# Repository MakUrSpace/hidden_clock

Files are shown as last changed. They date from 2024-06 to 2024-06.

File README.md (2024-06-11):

# [Hidden Clock](https://github.com/makurspace/hidden_clock)

This is a project to build clock. Driven by a ESP32C3, using a 3D printed light diffuser and a NeoPixel LED ring, this clock will display the hour and minute as shadowed numbers in glowing hexagons.

### Working Example!
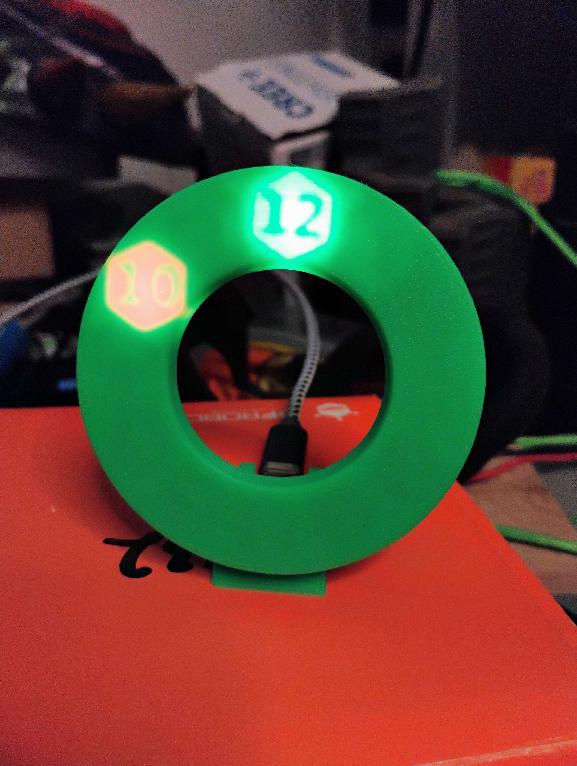
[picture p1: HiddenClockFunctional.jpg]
Working Hidden Clock


## External Parts

* [24x NeoPixel Ring](https://www.adafruit.com/product/1586)
  * A different ring could be used with if the Clockface Generator Notebook is appropriately configured. 
* [QT Py ESP32C3](https://www.adafruit.com/product/5405)
  * Pretty much any of the ESP32 QT Py's could run the firmware since it only needs 2 GPIO and an internal clock
 
## Code Dependencies

### [Clock Controller](clock.upy)
* [Micropython](https://micropython.org/)

### [Hidden Clockface Generator](HiddenClockfaceGenerator.md)

* [Jupyter](https://jupyter.org/)
* [OpenSCAD](https://openscad.org/)
* [solidpython](https://github.com/SolidCode/SolidPython)
* [viewscad](https://github.com/nickc92/ViewSCAD)

## Inspirations

I had been playing with lithophanes a lot ([such as those from the Lithophane Maker](https://lithophanemaker.com/)) and became enamored with how a thick-but-not-too-thick light difuser could cause an image to disappear without a backlight. The effect made static surfaces able to pop with hidden messages. I made some concept pieces out of wood that confirmed the basic idea. And then, toying with a NeoPixel ring one day, the idea of a light diffuser based clock came together.

## Hidden Clockface Model

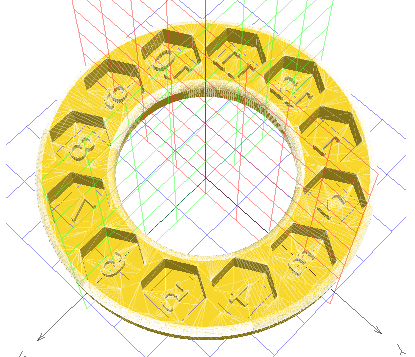
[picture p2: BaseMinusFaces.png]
Hidden Clockface


## Assembly Instructions

1. Print [Hidden Clockface](HiddenClockface.stl), [Clock Stomach](ClockStomach.stl) and [Embedded Button](EmbeddedButton.stl)
1. Load [clock.upy](clock.upy) firmware onto [Micropython formatted](https://micropython.org/download/ESP32_GENERIC_C3/) QT Py ESP32C3
1. Solder 3-wire connector cable from [24x NeoPixel Ring](https://www.adafruit.com/product/1586) to the [5V, GND, and M0 pins](https://learn.adafruit.com/adafruit-qt-py-esp32-c3-wifi-dev-board/pinouts) of the [QT Py ESP32C3](https://www.adafruit.com/product/5405)
       * Guarantee NeoPixel ring works and responds to both short and long button presses.
1. Glue [24x NeoPixel Ring](https://www.adafruit.com/product/1586) to [Clock Stomach](ClockStomach.stl)
1. Place [QT Py ESP32C3](https://www.adafruit.com/product/5405) into  [Clock Stomach](ClockStomach.stl) slot and solder-plasticweld the [Embedded Button](EmbeddedButton.stl) into place -- MINDFUL OF BUTTON PLACEMENT --
2. Solder/plasticweld [Hidden Clockface](HiddenClockface.stl) to [Clock Stomach](ClockStomach.stl) in front of [24x NeoPixel Ring](https://www.adafruit.com/product/1586)

## Control Instructions

* Short press (<200 milliseconds) adds a 3 minute modifier to the internal time
* Long press (>200 milliseconds) adds a 1 hour modifier to the internal time

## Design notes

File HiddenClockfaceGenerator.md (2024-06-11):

# Hidden Clockface Generator

This notebook builds a 3D model for a NeoPixel Ring clockface light diffuser

## Dependencies
* [OpenSCAD](https://openscad.org/)
* [solidpython](https://github.com/SolidCode/SolidPython)
* [viewscad](https://github.com/nickc92/ViewSCAD)

Let's import our dependencies

```python
import solid as s
import viewscad
```

And initialize the viewscad renderer

```python
r = viewscad.Renderer()
```

It's a commonly known requirment of baking apple pies that you must first define the universe, and a clockface is no different. This clockface definition builds off of 4 constants, defined below in millimeters.

```python
base_radius = 7.5    # Radius of the Individual Number Faces
num_height = 2       # Height of the number in the Number Face
shade_height = 1.5   # Thickness of the difuser
clock_height = 5     # Total Height/thickness of the clockface
```

The next 7 variables are simply derived from the initial constants

```python
hex_height = clock_height + 2           # Height of the number foace; has to be larger than the clock to make an opening through the base clockface shape
inner_radius = base_radius * 3          # Defines the radius of the donut hole in the clockface
between = base_radius * 2               # Defines the distance between inner and outer radii of the clockface
outer_radius = inner_radius + between   # Defines the total radius of the clockface, from center to edge
number_font_size = base_radius * 0.8    # Defines the font size of the number face
number_center_x_shift = number_font_size / 1.2
number_center_y_shift = -(base_radius * 0.8) / 2
```

```python
def build_face():
    return s.rotate([0, 0, 90])(s.cylinder(r=base_radius, h=hex_height, segments=6))
```

```python
def build_number_face(number):
    extruded_number = s.linear_extrude(num_height)(s.text(f"{number:2}", size=number_font_size))
    return s.rotate([0, 0, 90])(build_face() - s.translate([number_center_x_shift, number_center_y_shift, 0])(s.mirror([1, 0, 0])(extruded_number)))
```

```python
r.render(build_number_face(12))
```
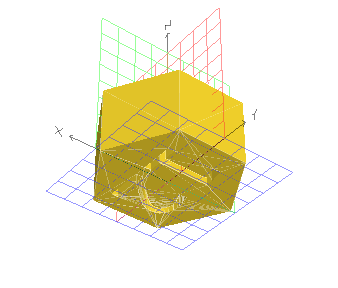
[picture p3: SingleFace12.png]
Single Number Face -- 12


```python
faces = sum([
    s.rotate([0, 0, i * -30])(
        s.translate([-4 * base_radius, 0, 0])(s.rotate([0, 0, i * 30])(
            build_number_face(i)))) for i in range(12, 0, -1)])
```

```python
r.render(faces)
```
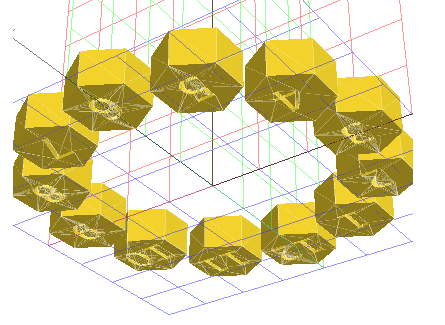
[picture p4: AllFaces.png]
All Faces


```python
base = s.rotate_extrude(segments=256)(s.translate([inner_radius, 0, 0])(s.hull()(
    s.circle(r=clock_height / 4) +
    s.translate([between, 0, 0])(s.circle(r=clock_height / 4)) +
    s.translate([between, clock_height, 0])(s.circle(r=clock_height / 3)) +
    s.translate([0, clock_height, 0])(s.circle(r=clock_height / 3)))))
```

```python
clock = base - s.translate([0, 0, shade_height])(faces)

r.render(base - faces, outfile="HiddenClockface.stl")
```
Hidden Clockface

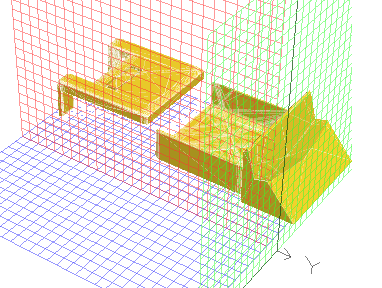
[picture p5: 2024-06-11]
Clockbase.png

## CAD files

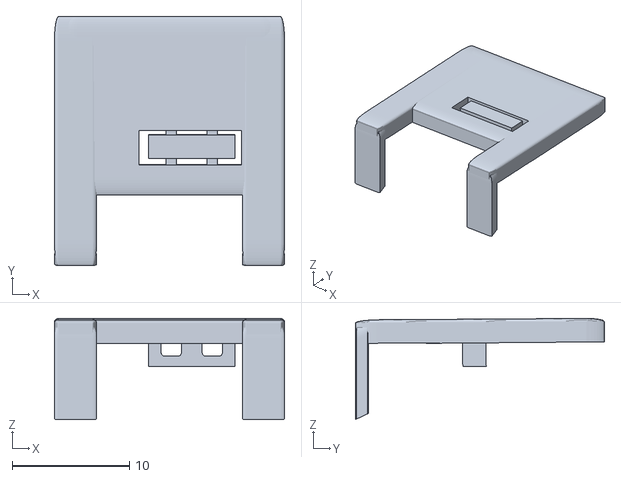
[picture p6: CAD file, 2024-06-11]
EmbeddedButton.stl
19.6 x 21.2 x 8.60

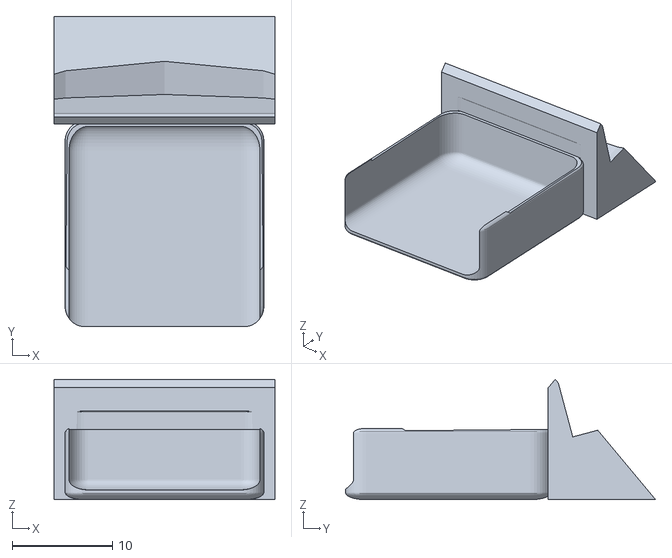
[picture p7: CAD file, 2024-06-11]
ClockStomach.stl
22.0 x 30.9 x 12.0
